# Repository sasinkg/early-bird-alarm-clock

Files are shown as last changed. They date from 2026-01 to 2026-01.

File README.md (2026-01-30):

# Early Bird Alarm Clock ⏰🚗

An interactive, mobile alarm clock designed to **force users out of bed** by combining physical movement, obstacle avoidance, and cognitive engagement. When the alarm triggers, the clock **drives away from the user** and can only be silenced by solving a math problem.

This project was completed as part of **ECE 445 – Senior Design** (Fall 2022).

---
###  Codebase: https://github.com/siddharthsharma123/ECE445.git
## 🧠 Motivation

Many people rely on repeated alarms and snoozing, which disrupts sleep cycles and reduces morning alertness. The Early Bird Alarm Clock addresses this by:
- Physically forcing the user to get out of bed
- Preventing passive alarm dismissal
- Engaging the user cognitively before silencing the alarm

---

## ✨ Features

- ⏱️ **Fully functional alarm clock**
  - Set current time and alarm time
  - Visual alarm status indicator
- 🚗 **Autonomous movement**
  - Dual DC motors with H-bridge control
  - Obstacle detection via ultrasonic sensors
- 🧮 **Math-based alarm shutdown**
  - Randomly generated arithmetic problem
  - Alarm silences only after correct solution
- 📟 **LCD-based user interface**
  - Clock display
  - Alarm configuration
  - Math problem interaction
- 🔊 **Audible alarm via piezo buzzer**

---

## 🏗️ System Architecture

The system is organized into four primary subsystems:

### 1. UI Module
- 16x2 LCD display
- 8 push buttons (clock control + math input)
- Shift register (74HC165) to reduce I/O pin usage

### 2. Movement Module
- Two 12V DC motors
- L298N dual H-bridge motor driver
- Three HC-SR04 ultrasonic sensors for obstacle avoidance

### 3. Math Module
- Random arithmetic problem generation
- Button-driven numerical input (hundreds / tens / ones)
- Answer verification logic

### 4. Power Module
- Multiple NiMH batteries
- Voltage regulation for logic (5V) and motors (12V)

---

## 🧩 Software Overview

The firmware is written in **C/C++ (Arduino)** and organized modularly:

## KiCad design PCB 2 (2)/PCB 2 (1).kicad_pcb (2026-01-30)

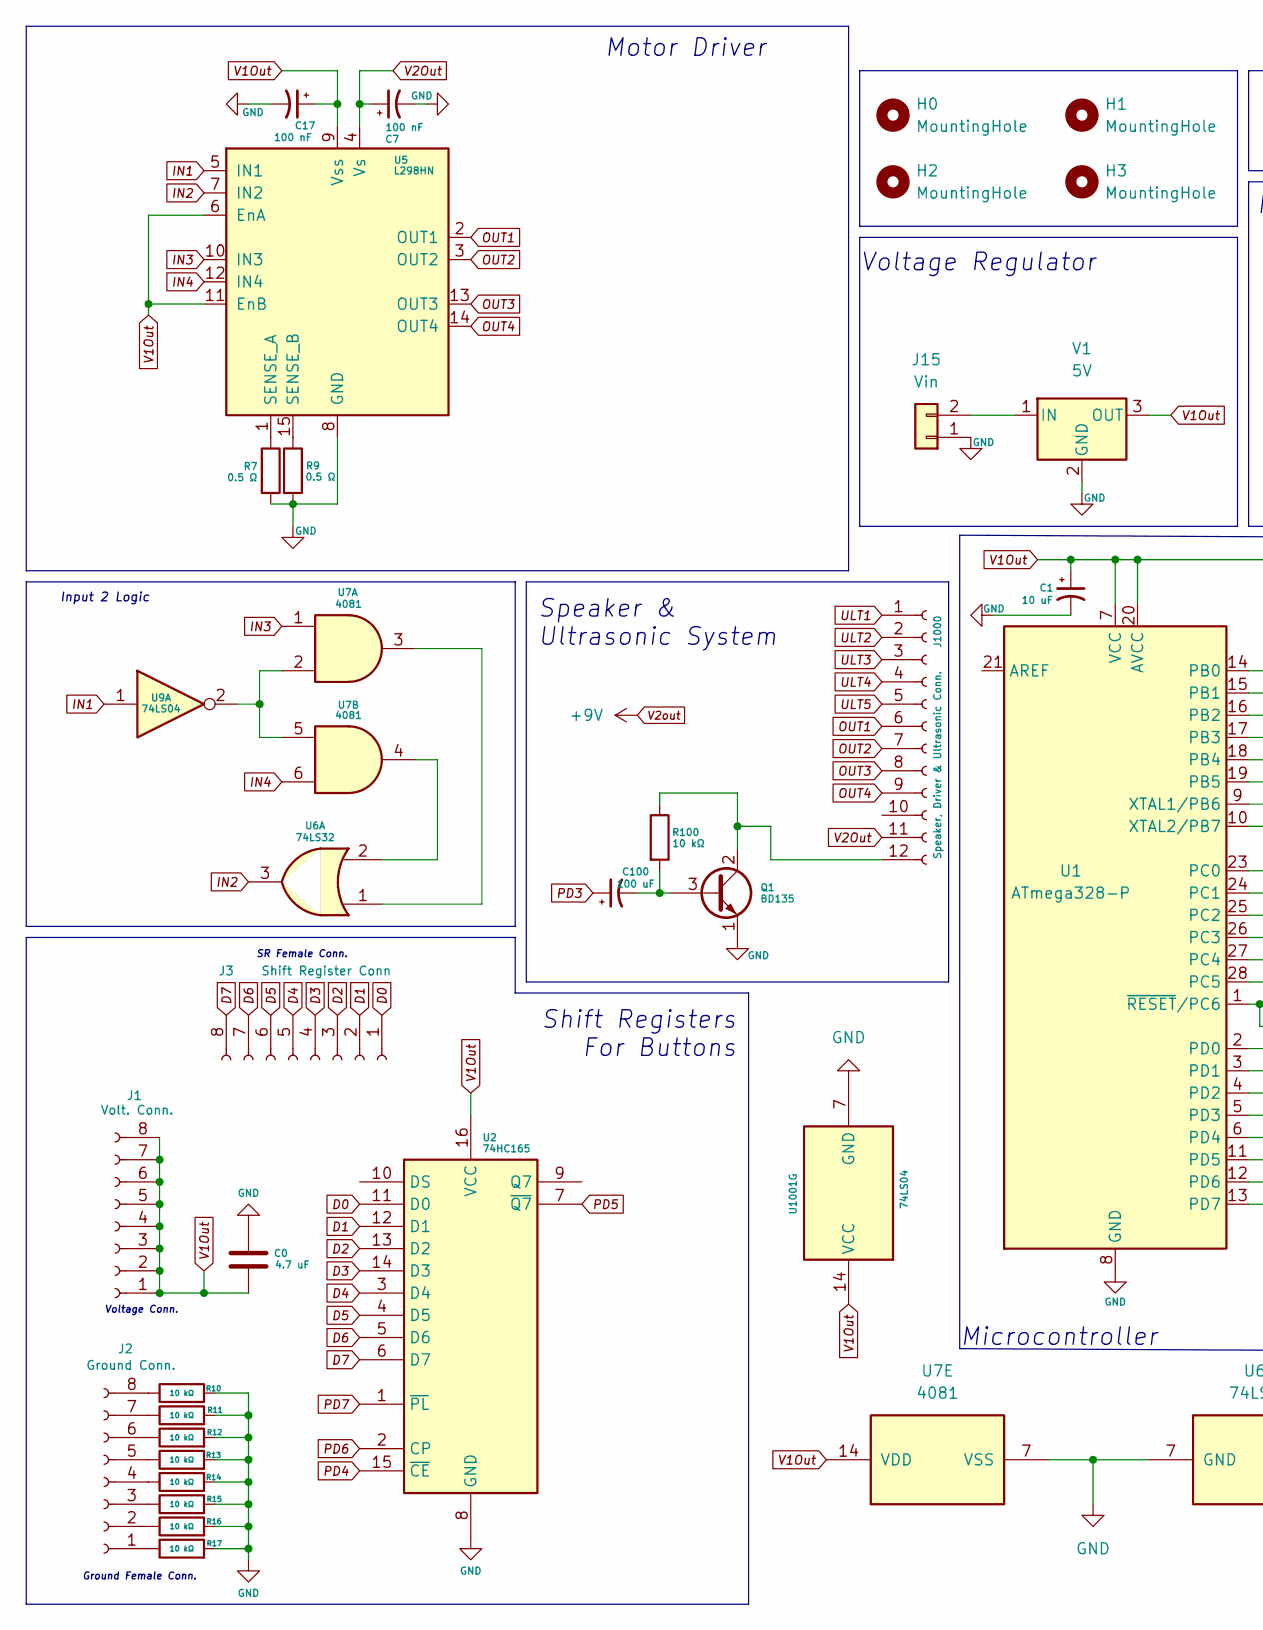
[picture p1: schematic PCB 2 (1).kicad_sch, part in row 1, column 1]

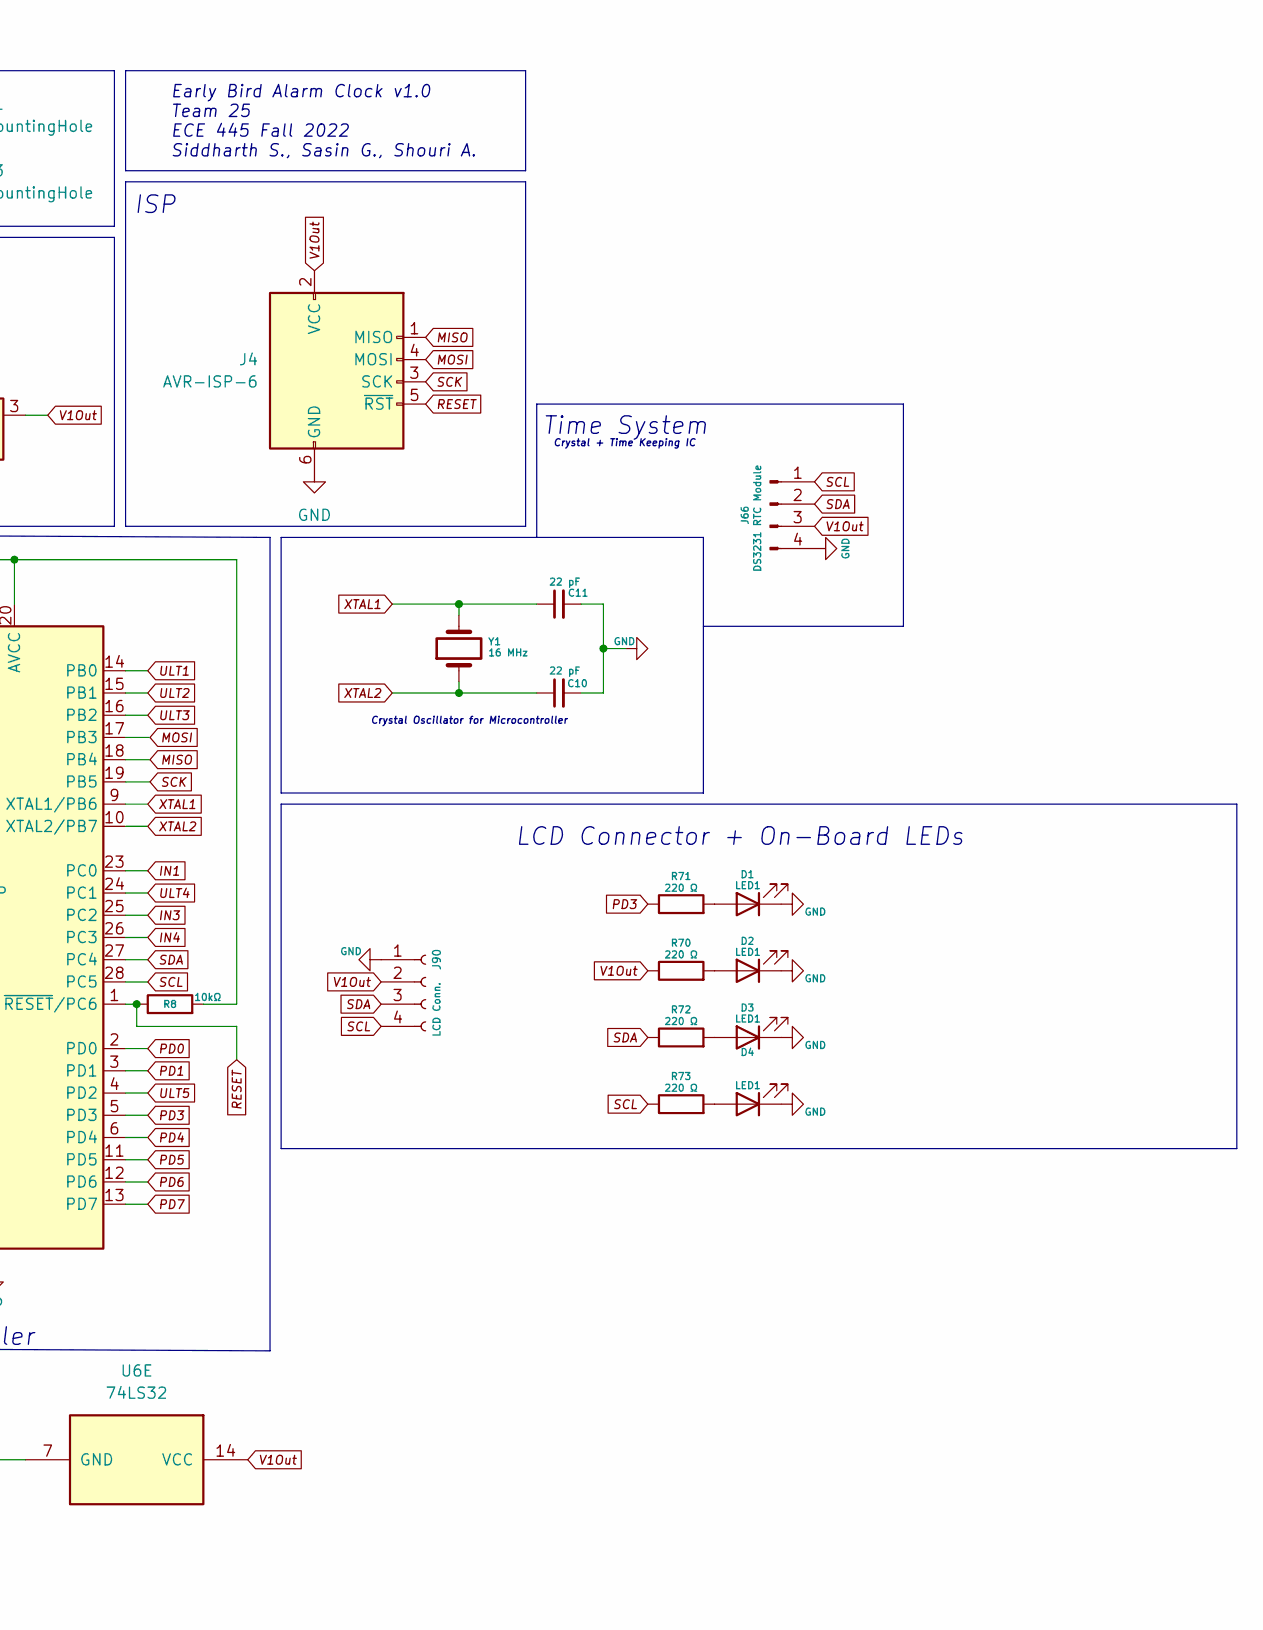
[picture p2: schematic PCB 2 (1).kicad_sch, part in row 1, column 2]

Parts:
C0: 4.7 uF; CP_Elec_3x5.3
C1: 10 uF; CP_Elec_3x5.3
C7, C17: 100 nF; CP_Elec_3x5.3
C10, C11: 22 pF; CP_Elec_3x5.3
C100: 100 uF; CP_Elec_3x5.3
D1, D2, D3, D4: LED1; LED_D1.8mm_W1.8mm_H2.4mm_Horizontal_O1.27mm_Z1.6mm
H0, H1, H2, H3: MountingHole; MountingHole_3.2mm_M3
J1: Volt. Conn.; 61300811821
J2: Ground Conn.; 61300811821
J3: Shift Register Conn; 61300811821
J4: AVR-ISP-6; IDC-Header_2x03_P2.54mm_Vertical
J15: Vin; Molex_CLIK-Mate_502382-0270_1x02-1MP_P1.25mm_Vertical
J66: DS3231 RTC Module; PinSocket_1x04_P2.54mm_Vertical
J90: LCD Conn.; PinHeader_1x04_P2.54mm_Vertical
J1000: Speaker, Driver & Ultrasonic Conn.; PinHeader_1x12_P2.54mm_Vertical
Q1: BD135; TO-126-3_Vertical
R7, R9: 0.5 Ω; R_0805_2012Metric_Pad1.20x1.40mm_HandSolder
R8: 10kΩ; R_0805_2012Metric_Pad1.20x1.40mm_HandSolder
R10, R11, R12, R13, R14, R15, R16, R17, R100: 10 kΩ; R_0805_2012Metric_Pad1.20x1.40mm_HandSolder
R70, R71, R72, R73: 220 Ω; R_0805_2012Metric_Pad1.20x1.40mm_HandSolder
U1: ATmega328-P; DIP-28_W7.62mm
U2: 74HC165; SO-16
U5: L298HN; TO-220-15_P2.54x2.54mm_StaggerOdd_Lead5.84mm_TabDown
U6: 74LS32; DIP794W45P254L1969H508Q14
U7: 4081; DIP794W45P254L1969H508Q14
U9, U1001: 74LS04; DIP794W46P254L1969H533Q14
V1: 5V; TO254P1054X470X2600-3
Y1: 16 MHz; XTAL_HC49P488W46L1150T500H350

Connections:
D0: J3.1, U2.11 (D0)
D1: J3.2, U2.12 (D1)
D2: J3.3, U2.13 (D2)
D3: J3.4, U2.14 (D3)
D4: J3.5, U2.3 (D4)
D5: J3.6, U2.4 (D5)
D6: J3.7, U2.5 (D6)
D7: J3.8, U2.6 (D7)
GND: C0.1, C1.2, C7.2, C10.2, C11.2, C17.2, D1.1 (K), D2.1 (K), D3.1 (K), D4.1 (K), J4.6 (GND), J15.1, J66.4, J90.1, Q1.1 (E), R7.2, R9.2, R10.2, R11.2, R12.2, R13.2, R14.2, R15.2, R16.2, R17.2, U1.8 (GND), U1.22 (GND), U2.8 (GND), U5.8 (GND), U6.7 (GND), U7.7 (VSS), U1001.7 (GND), V1.2 (GND)
IN1: U1.23 (PC0), U5.5 (IN1), U9.1
IN2: U5.7 (IN2), U6.3
IN3: U1.25 (PC2), U5.10 (IN3), U7.1
IN4: U1.26 (PC3), U5.12 (IN4), U7.6
MISO: J4.1 (MISO), U1.18 (PB4)
MOSI: J4.4 (MOSI), U1.17 (PB3)
unnamed: C100.2, Q1.3 (B), R100.2
unnamed: D1.2 (A), R71.2
unnamed: D2.2 (A), R70.2
unnamed: D3.2 (A), R72.2
unnamed: D4.2 (A), R73.2
unnamed: J2.1, R17.1
unnamed: J2.2, R16.1
unnamed: J2.3, R15.1
unnamed: J2.4, R14.1
unnamed: J2.5, R13.1
unnamed: J2.6, R12.1
unnamed: J2.7, R11.1
unnamed: J2.8, R10.1
unnamed: J15.2, V1.1 (IN)
unnamed: J1000.12, Q1.2 (C), R100.1
unnamed: R7.1, U5.1 (SENSE_A)
unnamed: R9.1, U5.15 (SENSE_B)
unnamed: U6.1, U7.3
unnamed: U6.2, U7.4
unnamed: U7.2, U7.5, U9.2
OUT1: J1000.6, U5.2 (OUT1)
OUT2: J1000.7, U5.3 (OUT2)
OUT3: J1000.8, U5.13 (OUT3)
OUT4: J1000.9, U5.14 (OUT4)
PD0: U1.2 (PD0)
PD1: U1.3 (PD1)
PD3: C100.1, R71.1, U1.5 (PD3)
PD4: U1.6 (PD4), U2.15 (~CE)
PD5: U1.11 (PD5), U2.7 (~Q7)
PD6: U1.12 (PD6), U2.2 (CP)
PD7: U1.13 (PD7), U2.1 (~PL)
RESET: J4.5 (~RST), R8.1, U1.1 (~RESET/PC6)
SCK: J4.3 (SCK), U1.19 (PB5)
SCL: J66.1, J90.4, R73.1, U1.28 (PC5)
SDA: J66.2, J90.3, R72.1, U1.27 (PC4)
ULT1: J1000.1, U1.14 (PB0)
ULT2: J1000.2, U1.15 (PB1)
ULT3: J1000.3, U1.16 (PB2)
ULT4: J1000.4, U1.24 (PC1)
ULT5: J1000.5, U1.4 (PD2)
V1Out: C0.2, C1.1, C17.1, J1.1, J1.2, J1.3, J1.4, J1.5, J1.6, J1.7, J1.8, J4.2 (VCC), J66.3, J90.2, R8.2, R70.1, U1.7 (VCC), U1.20 (AVCC), U2.16 (VCC), U5.6 (EnA), U5.9 (Vss), U5.11 (EnB), U6.14 (VCC), U7.14 (VDD), U1001.14 (VCC), V1.3 (OUT)
V2Out: C7.1, J1000.11, U5.4 (Vs)
XTAL1: C11.1, U1.9 (XTAL1/PB6), Y1.2
XTAL2: C10.1, U1.10 (XTAL2/PB7), Y1.1

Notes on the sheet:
Shift Registers For Buttons
Crystal Oscillator for Microcontroller
LCD Connector + On-Board LEDs
Voltage Regulator
ISP
Crystal + Time Keeping IC
Speaker & Ultrasonic System
Input 2 Logic
Time System
Voltage Conn.
SR Female Conn.
Microcontroller
Motor Driver
Early Bird Alarm Clock v1.0 Team 25 ECE 445 Fall 2022 Siddharth S., Sasin G., Shouri A.
Ground Female Conn.

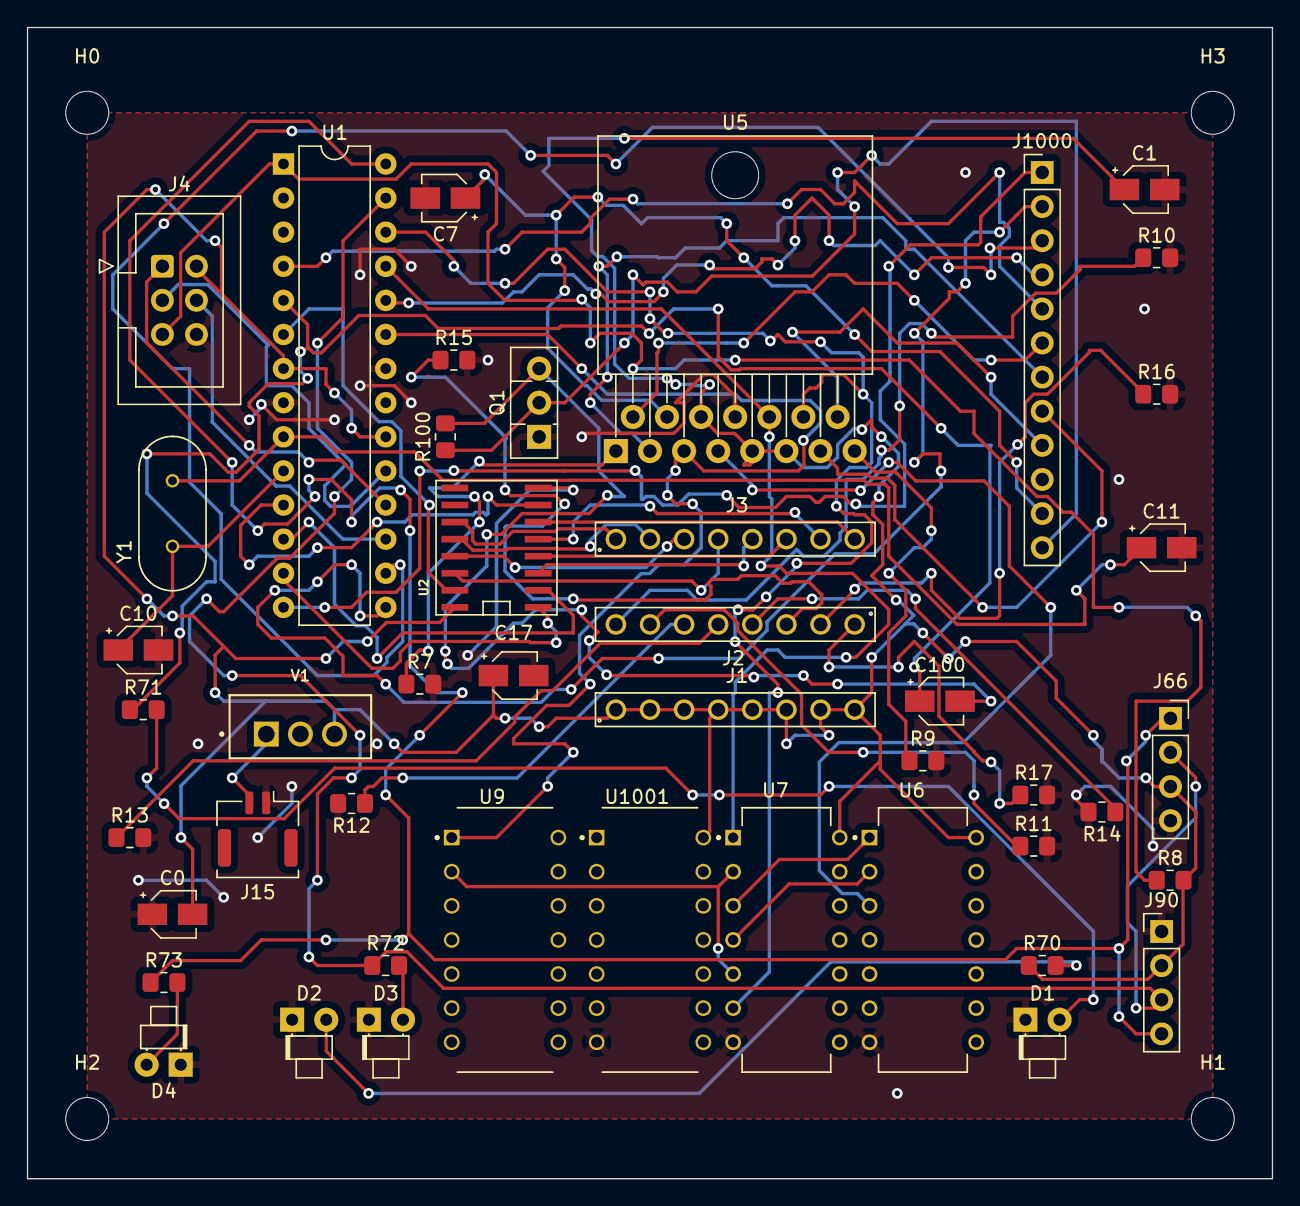
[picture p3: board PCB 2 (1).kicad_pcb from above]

Board: 2 copper layers, 92.7 x 85.7 mm, 49 parts (0 on the bottom side), 57 nets.
